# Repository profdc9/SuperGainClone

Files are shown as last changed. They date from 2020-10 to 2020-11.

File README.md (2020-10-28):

# Stereo Super Gain Clone layout

This is a two-channel PCB layout for the LM3886-based Super Gain Clone by Bob Cordell.  It can be found in Chapter 27 in his book "Audio Amplifiers."

This project layout separates signal and power grounds as specified in the schematic.  It is intended to be a compact layout that will fit in a small amplifier case.  The two input ground should be joined where they enter the chassis, as they are not joined on the PCB except for hum breakers resistors.  The PCB is made available under the Creative Commons CC-BY-SA 4.0 license.

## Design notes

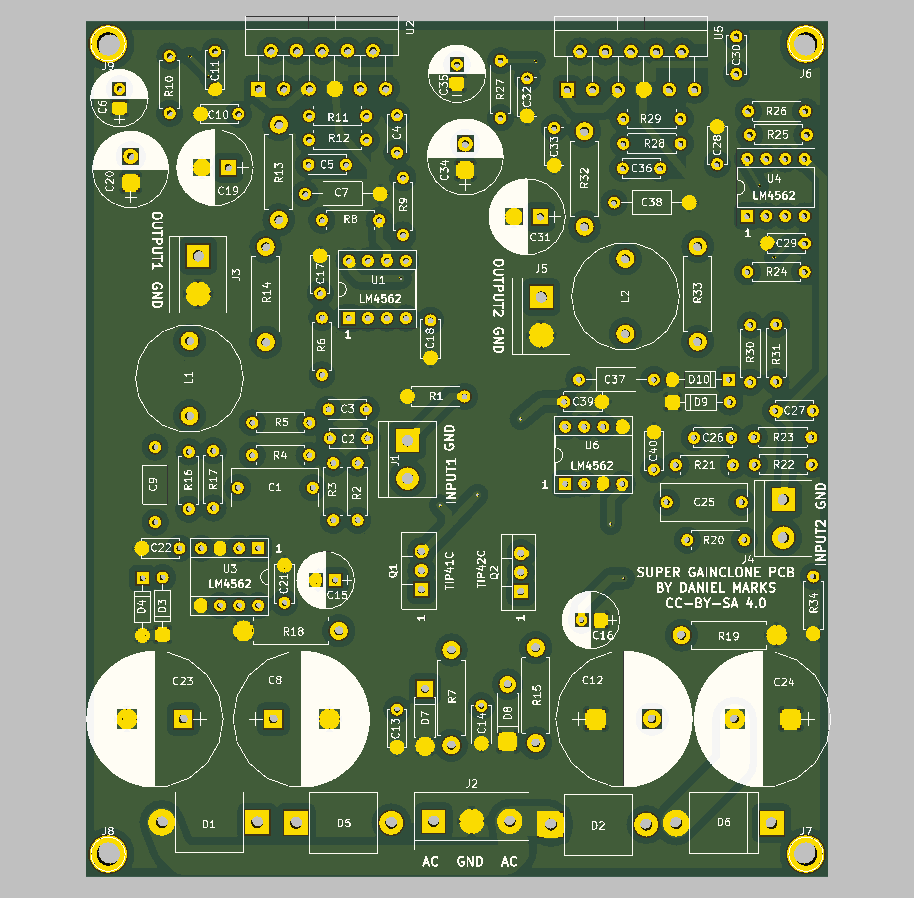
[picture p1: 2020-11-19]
SuperGainClone.png

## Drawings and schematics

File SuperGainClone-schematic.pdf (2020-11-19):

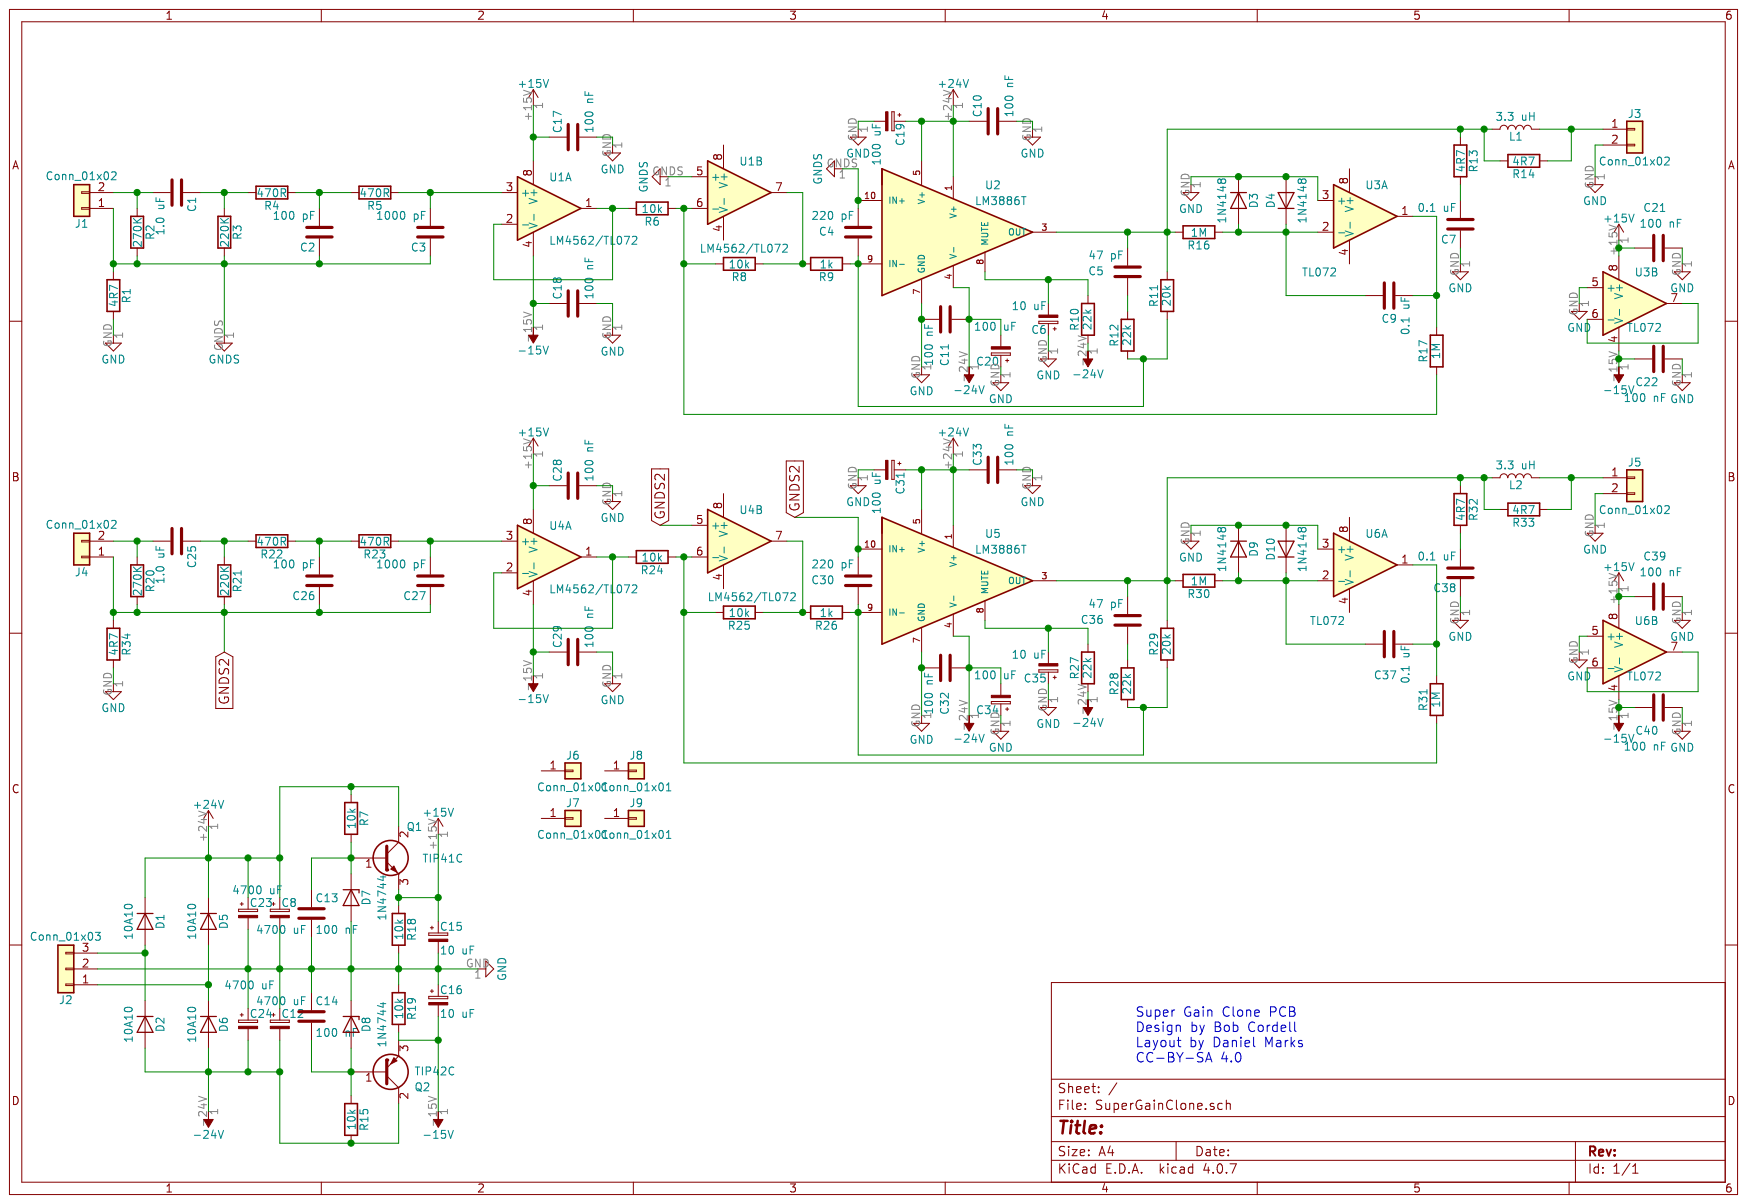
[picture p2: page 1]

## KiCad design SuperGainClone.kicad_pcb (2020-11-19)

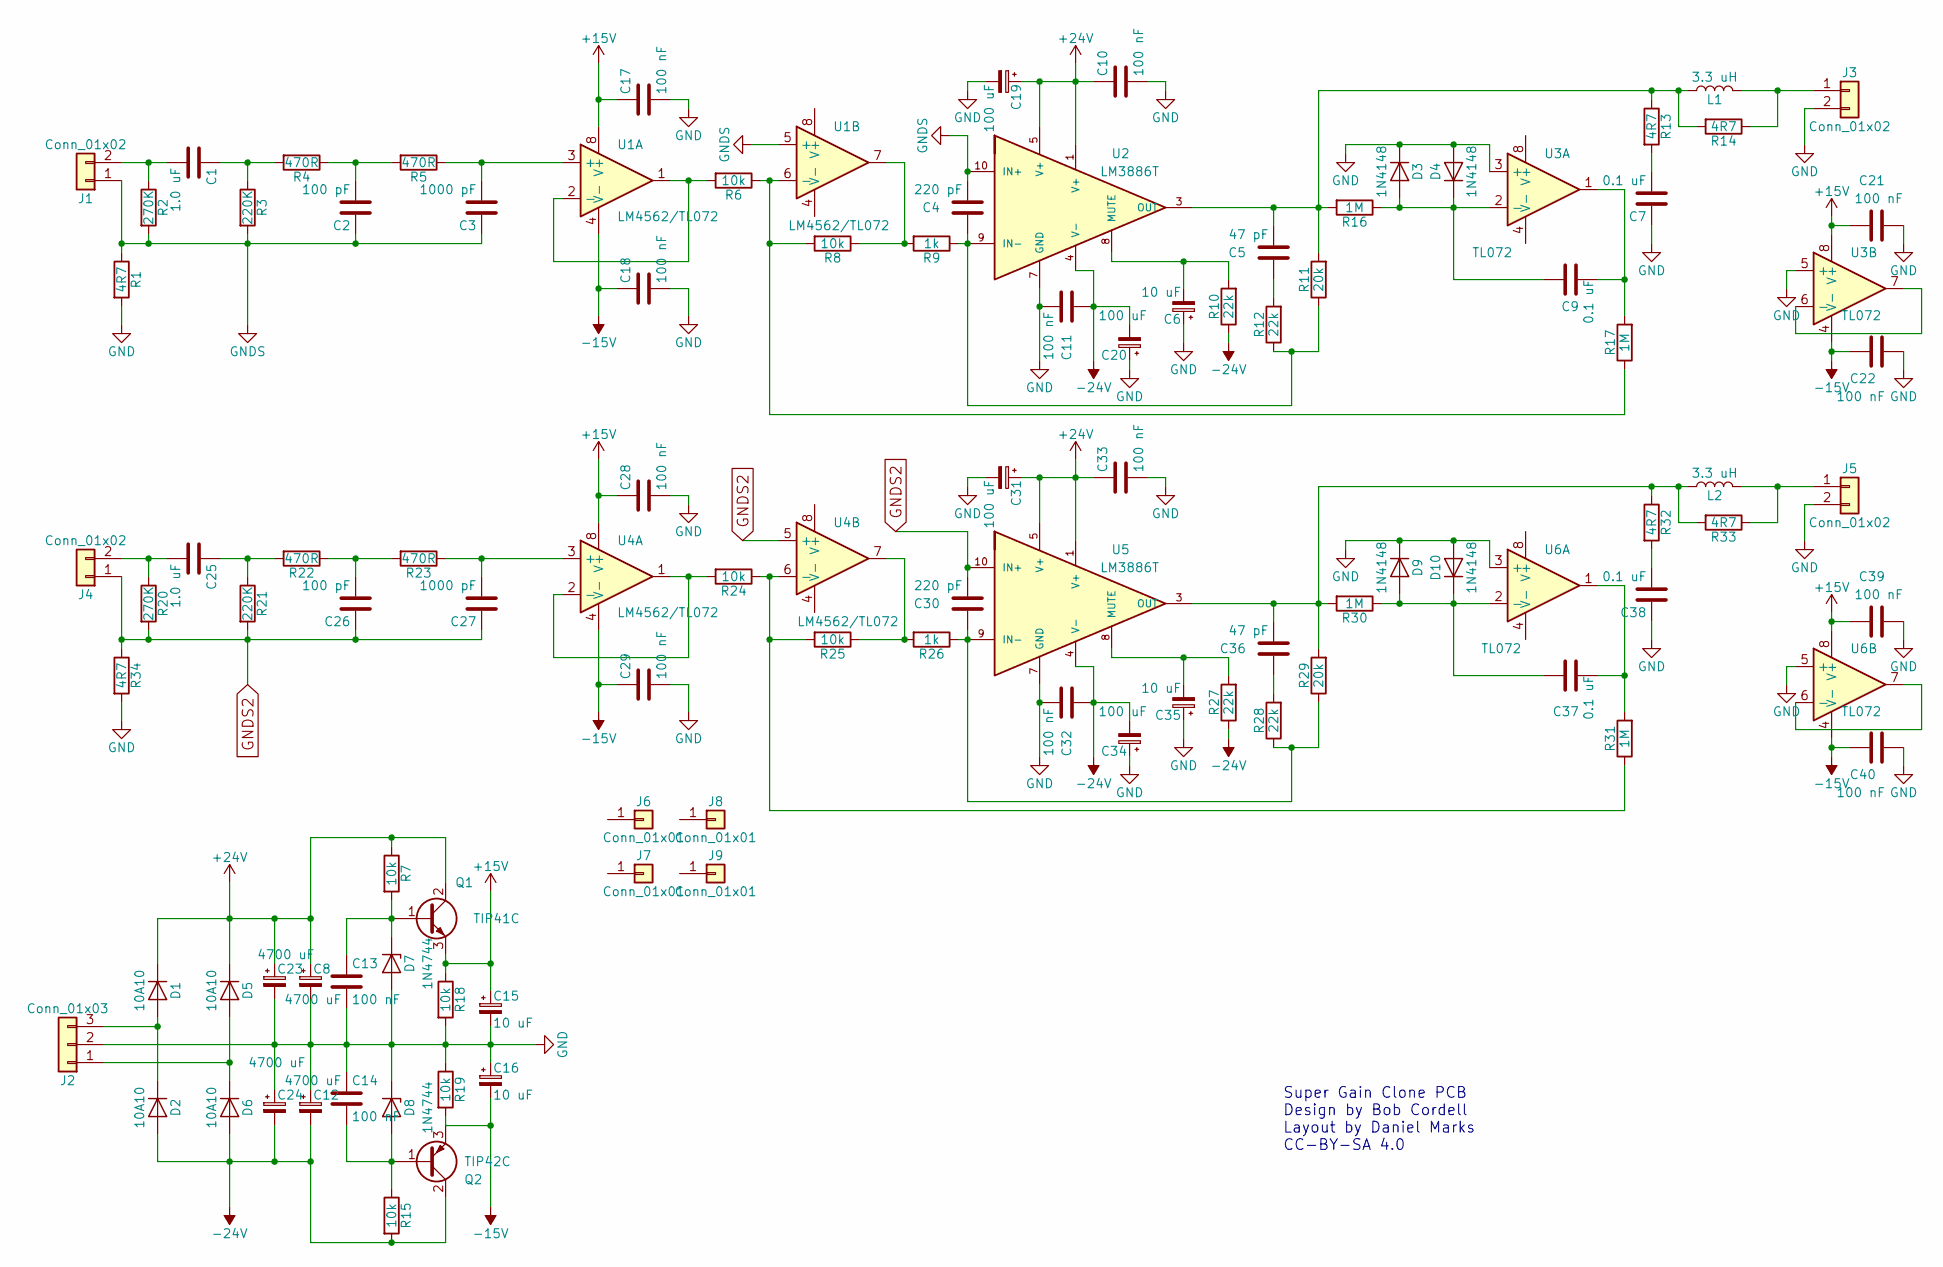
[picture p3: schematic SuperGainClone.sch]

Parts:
C1, C25: 1.0 uF; C_Rect_L11.5mm_W5.0mm_P10.00mm_MKT
C2, C26: 100 pF; C_Disc_D5.0mm_W2.5mm_P5.00mm
C3, C27: 1000 pF; C_Disc_D5.0mm_W2.5mm_P5.00mm
C4, C30: 220 pF; C_Disc_D5.0mm_W2.5mm_P5.00mm
C5, C36: 47 pF; C_Disc_D5.0mm_W2.5mm_P5.00mm
C6, C15, C16, C35: 10 uF; CP_Radial_D7.5mm_P2.50mm
C7, C9, C37, C38: 0.1 uF; C_Axial_L5.1mm_D3.1mm_P10.00mm_Horizontal
C8, C12, C23, C24: 4700 uF; CP_Radial_D18.0mm_P7.50mm
C10, C11, C13, C14, C17, C18, C21, C22, C28, C29, C32, C33, C39, C40: 100 nF; C_Disc_D5.0mm_W2.5mm_P5.00mm
C19, C20, C31, C34: 100 uF; CP_Radial_D10.0mm_P3.50mm
D1, D2, D5, D6: 10A10; D_5KPW_P12.70mm_Horizontal
D3, D4, D9, D10: 1N4148; D_DO-35_SOD27_P7.62mm_Horizontal
D7, D8: 1N4744; D_DO-41_SOD81_P7.62mm_Horizontal
J1, J3, J4, J5: Conn_01x02; TerminalBlock_bornier-2_P5.08mm
J2: Conn_01x03; TerminalBlock_bornier-3_P5.08mm
J6, J7, J8, J9: Conn_01x01; 1pin
L1, L2: 3.3 uH; L_Radial_D14.2mm_P10.00mm_Neosid_SD14
Q1: TIP41C; TO-220-3_Vertical
Q2: TIP42C; TO-220-3_Vertical
R1, R34: 4R7; R_Axial_DIN0207_L6.3mm_D2.5mm_P7.62mm_Horizontal
R2, R20: 270K; R_Axial_DIN0207_L6.3mm_D2.5mm_P7.62mm_Horizontal
R3, R21: 220K; R_Axial_DIN0207_L6.3mm_D2.5mm_P7.62mm_Horizontal
R4, R5, R22, R23: 470R; R_Axial_DIN0207_L6.3mm_D2.5mm_P7.62mm_Horizontal
R6, R8, R24, R25: 10k; R_Axial_DIN0207_L6.3mm_D2.5mm_P7.62mm_Horizontal
R7, R15, R18, R19: 10k; R_Axial_DIN0411_L9.9mm_D3.6mm_P12.70mm_Horizontal
R9, R26: 1k; R_Axial_DIN0207_L6.3mm_D2.5mm_P7.62mm_Horizontal
R10, R12, R27, R28: 22k; R_Axial_DIN0207_L6.3mm_D2.5mm_P7.62mm_Horizontal
R11, R29: 20k; R_Axial_DIN0207_L6.3mm_D2.5mm_P7.62mm_Horizontal
R13, R14, R32, R33: 4R7; R_Axial_DIN0411_L9.9mm_D3.6mm_P12.70mm_Horizontal
R16, R17, R30, R31: 1M; R_Axial_DIN0207_L6.3mm_D2.5mm_P7.62mm_Horizontal
U1, U4: LM4562/TL072; DIP-8_W7.62mm_Socket
U2, U5: LM3886T; TO-220-11_Vertical_StaggeredType1
U3, U6: TL072; DIP-8_W7.62mm_Socket

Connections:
+15V: C15.1, C17.1, C21.1, C28.1, C39.1, Q1.3 (E), R18.1, U1.8 (V+), U3.8 (V+), U4.8 (V+), U6.8 (V+)
+24V: C8.1, C10.1, C19.1, C23.1, C31.1, C33.1, D1.1 (K), D5.1 (K), Q1.2 (C), R7.1, U2.1 (V+), U2.5 (V+), U5.1 (V+), U5.5 (V+)
-15V: C16.2, C18.1, C22.1, C29.1, C40.1, Q2.3 (E), R19.2, U1.4 (V-), U3.4 (V-), U4.4 (V-), U6.4 (V-)
-24V: C11.1, C12.2, C20.2, C24.2, C32.1, C34.2, D2.2 (A), D6.2 (A), Q2.2 (C), R10.1, R15.2, R27.1, U2.4 (V-), U5.4 (V-)
GND: C6.1, C7.1, C8.2, C10.2, C11.2, C12.1, C13.2, C14.1, C15.2, C16.1, C17.2, C18.2, C19.2, C20.1, C21.2, C22.2, C23.2, C24.1, C28.2, C29.2, C31.2, C32.2, C33.2, C34.1, C35.1, C38.1, C39.2, C40.2, D3.1 (K), D4.2 (A), D7.2 (A), D8.1 (K), D9.1 (K), D10.2 (A), J2.2, J3.2, J5.2, R1.2, R18.2, R19.1, R34.2, U2.7 (GND), U3.3 (+), U3.5 (+), U5.7 (GND), U6.3 (+), U6.5 (+)
GNDS: C2.1, C3.1, C4.2, J1.1, R1.1, R2.2, R3.2, U1.5 (+), U2.10 (IN+)
GNDS2: C26.1, C27.1, C30.2, J4.1, R20.2, R21.2, R34.1, U4.5 (+), U5.10 (IN+)
unnamed: C1.1, R3.1, R4.2
unnamed: C1.2, J1.2, R2.1
unnamed: C2.2, R4.1, R5.2
unnamed: C3.2, R5.1, U1.3 (+)
unnamed: C4.1, R9.1, R11.1, R12.1, U2.9 (IN-)
unnamed: C5.1, R12.2
unnamed: C5.2, L1.1, R11.2, R13.1, R14.2, R16.2, U2.3 (OUT)
unnamed: C6.2, R10.2, U2.8 (MUTE)
unnamed: C7.2, R13.2
unnamed: C9.1, D3.2 (A), D4.1 (K), R16.1, U3.2 (-)
unnamed: C9.2, R17.2, U3.1
unnamed: C13.1, D7.1 (K), Q1.1 (B), R7.2
unnamed: C14.2, D8.2 (A), Q2.1 (B), R15.1
unnamed: C25.1, R21.1, R22.2
unnamed: C25.2, J4.2, R20.1
unnamed: C26.2, R22.1, R23.2
unnamed: C27.2, R23.1, U4.3 (+)
unnamed: C30.1, R26.1, R28.1, R29.1, U5.9 (IN-)
unnamed: C35.2, R27.2, U5.8 (MUTE)
unnamed: C36.1, R28.2
unnamed: C36.2, L2.1, R29.2, R30.2, R32.1, R33.2, U5.3 (OUT)
unnamed: C37.1, D9.2 (A), D10.1 (K), R30.1, U6.2 (-)
unnamed: C37.2, R31.2, U6.1
unnamed: C38.2, R32.2
unnamed: D1.2 (A), D2.1 (K), J2.3
unnamed: D5.2 (A), D6.1 (K), J2.1
unnamed: J3.1, L1.2, R14.1
unnamed: J5.1, L2.2, R33.1
unnamed: R6.2, U1.1, U1.2 (-)
unnamed: R8.1, R9.2, U1.7
unnamed: R6.1, R8.2, R17.1, U1.6 (-)
unnamed: R24.1, R25.2, R31.1, U4.6 (-)
unnamed: R24.2, U4.1, U4.2 (-)
unnamed: R25.1, R26.2, U4.7
unnamed: U3.6 (-), U3.7
unnamed: U6.6 (-), U6.7

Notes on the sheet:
Super Gain Clone PCB Design by Bob Cordell Layout by Daniel Marks CC-BY-SA 4.0

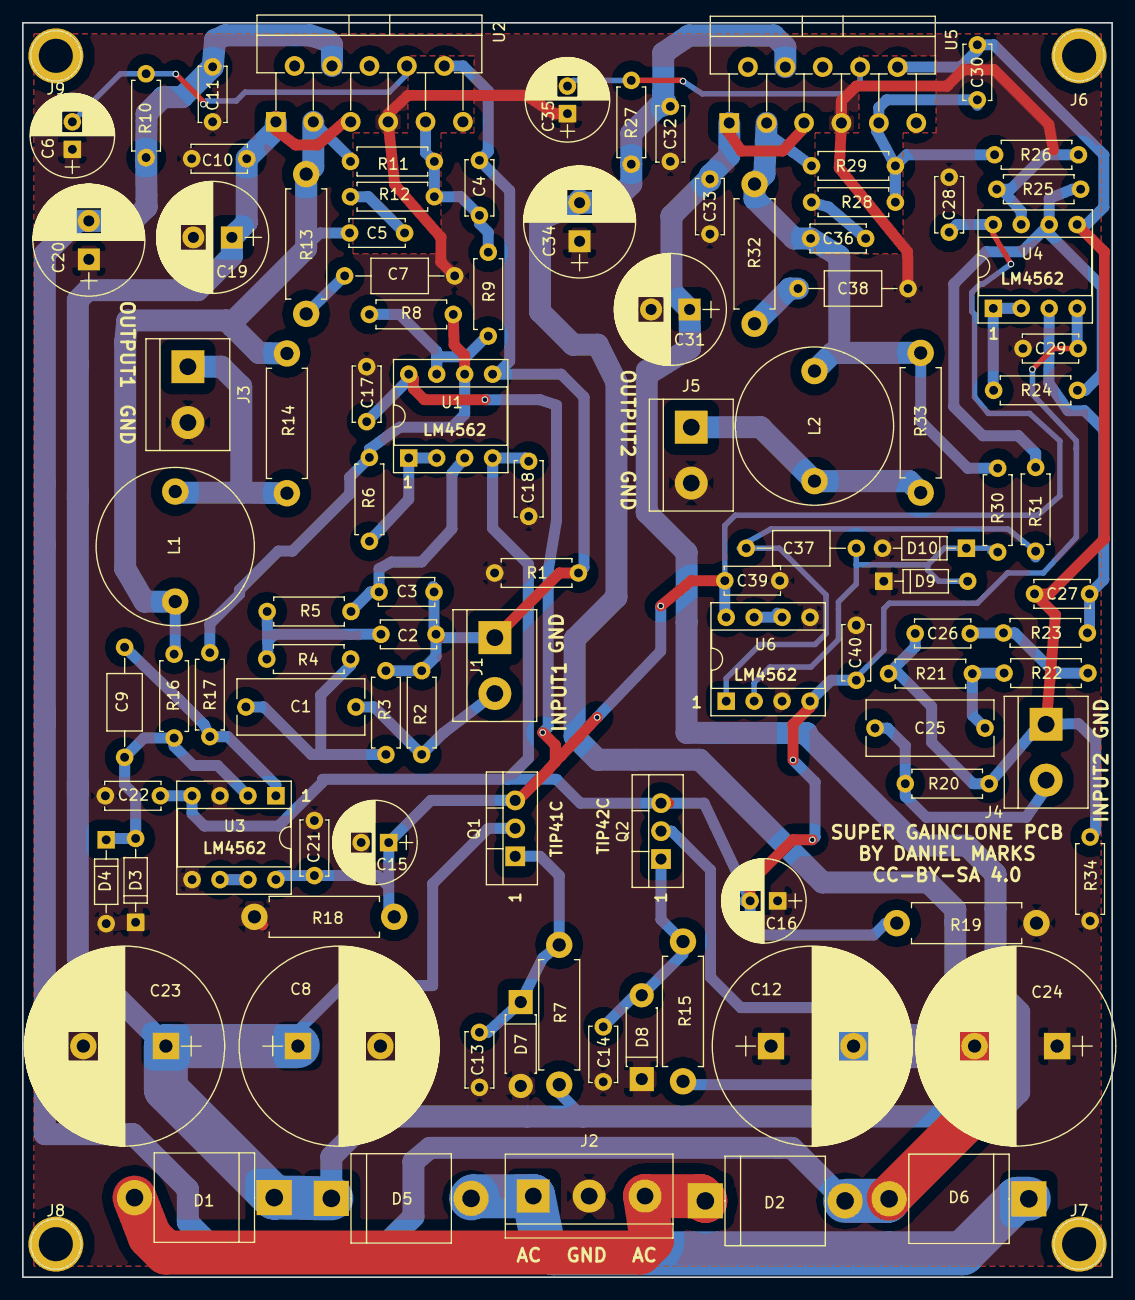
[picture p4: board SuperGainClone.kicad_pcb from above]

Board: 2 copper layers, 99.0 x 114.0 mm, 103 parts (0 on the bottom side), 43 nets.

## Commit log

2020-10-29 Rearranged some components
    [SuperGainClone-B.Cu.gbr, SuperGainClone-B.Mask.gbr, SuperGainClone-B.SilkS.gbr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]
2020-11-19 Fixed DC servo feedback
    [SuperGainClone-B.Cu.gbr, SuperGainClone-B.Mask.gbr, SuperGainClone-B.SilkS.gbr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]
